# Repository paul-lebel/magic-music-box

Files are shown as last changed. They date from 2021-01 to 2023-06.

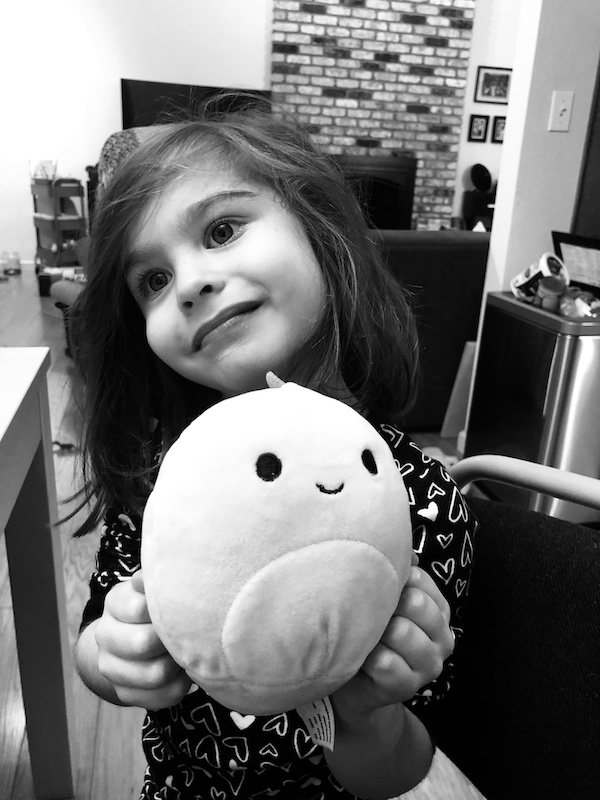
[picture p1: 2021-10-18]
Photos/SiaAndDave.jpg

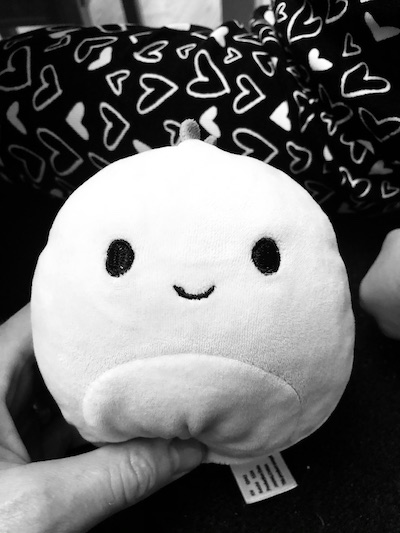
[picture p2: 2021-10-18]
Photos/Dave.jpg

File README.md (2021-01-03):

# magic-music-box
A small platform for parent-configurable child entertainment and education.

## Features
1. A small box with a simple screen, UI buttons, an audio system, and a lighting system.
2. A software platform that allows parents to create custom quiz questions (eg. "What does 5+5 equal?") or games.
3. A text to speech module reads the input prompts aloud through the audio speaker for children too young to read.
4. A bluetooth module allows for music streaming to the device from a parent's cellphone.
5. Computer control of the lighting system enhances the user experience for the child.
6. Customization of the underlying PCB's silkscreen artwork is displayed through a transparent front panel.

## Requirements
RPi.GPIO, inky, gTTS, circuitpython, adafruit-circuitpython-neopixel, font_fredoka_one

## Installation
This module was developed on Raspberry Pi Zero W V1.1, but should be compatible with all newer RPi models running the latest version of Raspbian OS.
1. Ensure the OS is updated, and also ensure that Python 3 is used by default. Following the instructions here takes care of this as well as circuitpython installation: <br>
https://learn.adafruit.com/circuitpython-on-raspberrypi-linux/installing-circuitpython-on-raspberry-pi
2. Follow these instructions to install inky: <br>
https://learn.pimoroni.com/tutorial/sandyj/getting-started-with-inky-phat
3. Add the following lines to /boot/config.txt: <br>
dtoverlay=audremap, enable_jack=on <br>
dtoverlay=audremap, pins_18_19=on <br>
dtoverlay=spi1-3cs <br>
4. Download / clone this repository
5. Navigate to the base of the repository
6. Install setuptools (__pip install setuptools__)
7. Install module (__pip install .__)

## Updating Module from Repository
1. Pull changes from remote repository
2. Activate virtual environment with previous install
3. Navigate to the module directory
4. Test the module for completeness (__python setup.py test__)
5. Update module (__pip install . --upgrade__)

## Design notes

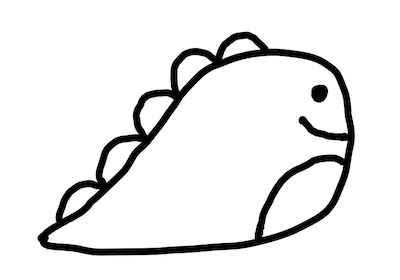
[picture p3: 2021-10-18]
Photos/Dave.png

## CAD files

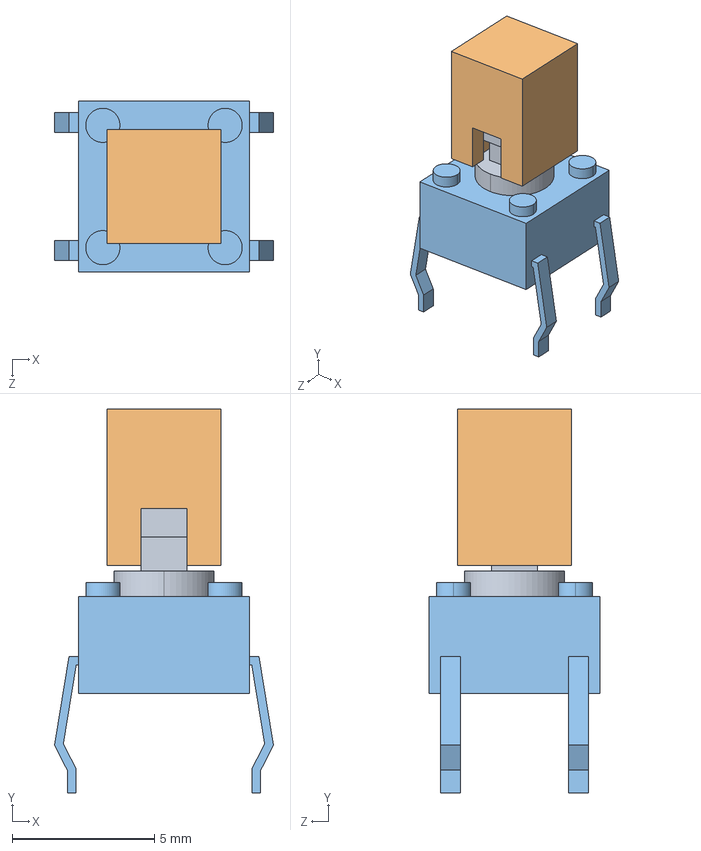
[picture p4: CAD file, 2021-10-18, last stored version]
RainbowPlay/B3F-1052/B3F-1052.step
7.70 x 13.5 x 6.00 mm
B3F_1052_BUTTON
B32_1000
B3F_1052_BASE

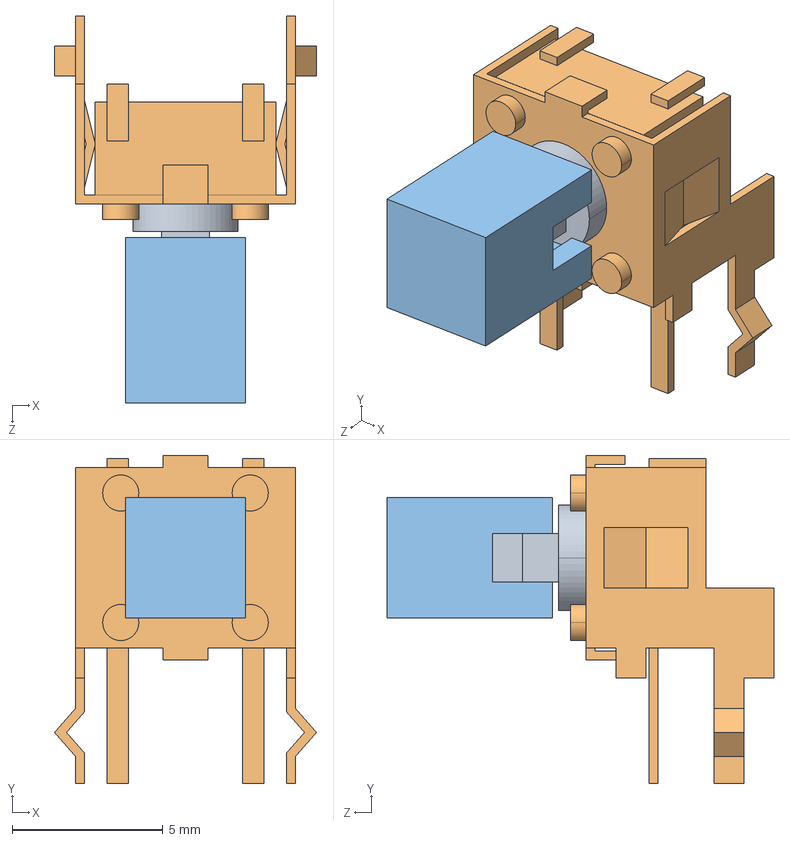
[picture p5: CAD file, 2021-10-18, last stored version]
RainbowPlay/B3F-3152/B3F-3152.step
8.70 x 10.9 x 12.9 mm
B3F_3152_BUTTON
B3F_3152_BASE
B32_1000

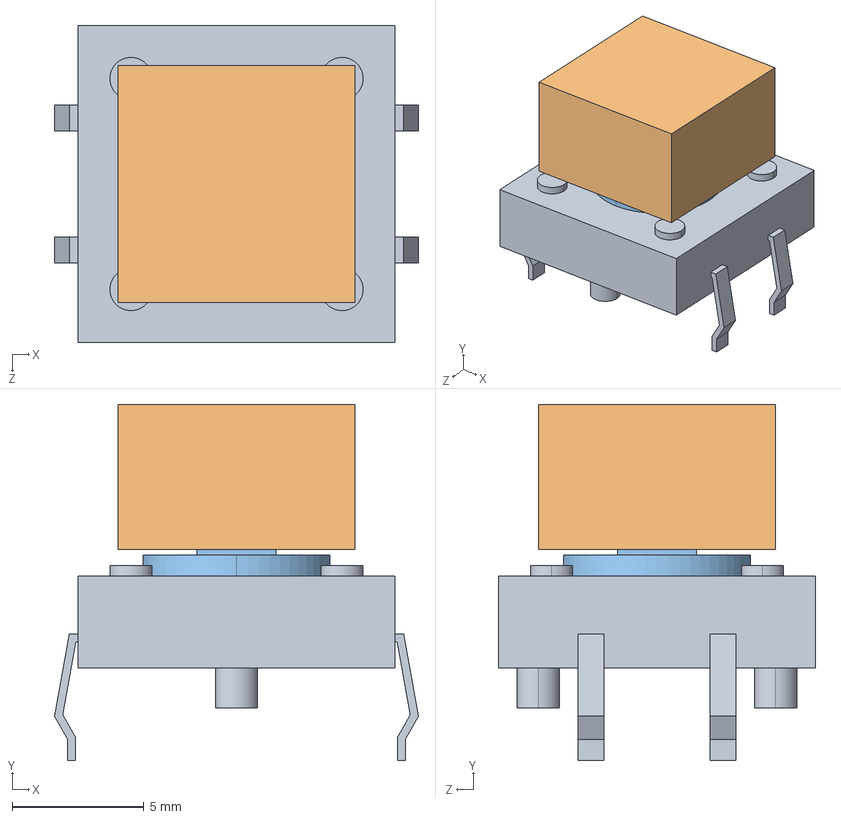
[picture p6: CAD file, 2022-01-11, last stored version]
RainbowPlay/B3F-4050/B3F-4050.step
13.8 x 13.5 x 12.0 mm
B3F_4050_BASE
B32_1200
B3F_4050_BUTTON

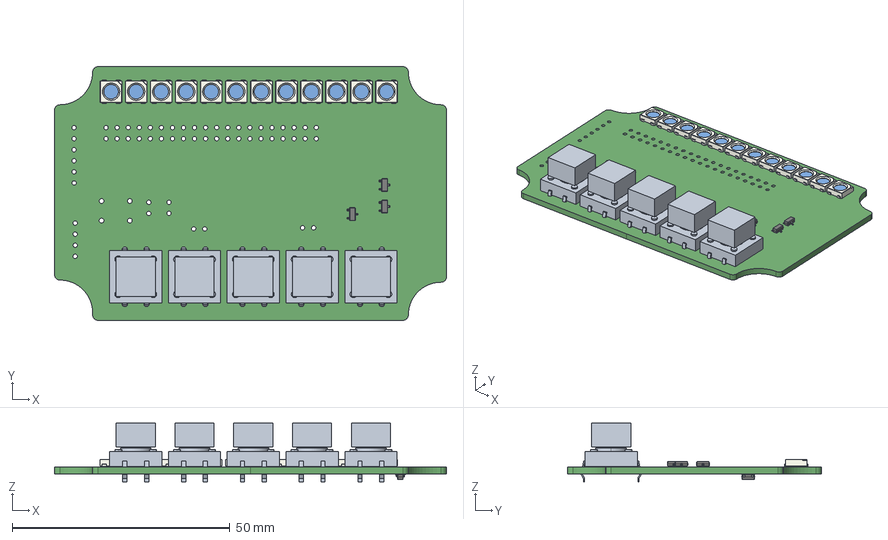
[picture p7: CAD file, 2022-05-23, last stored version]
RainbowPlay/RainbowPlay.step
90.0 x 58.2 x 13.5 mm

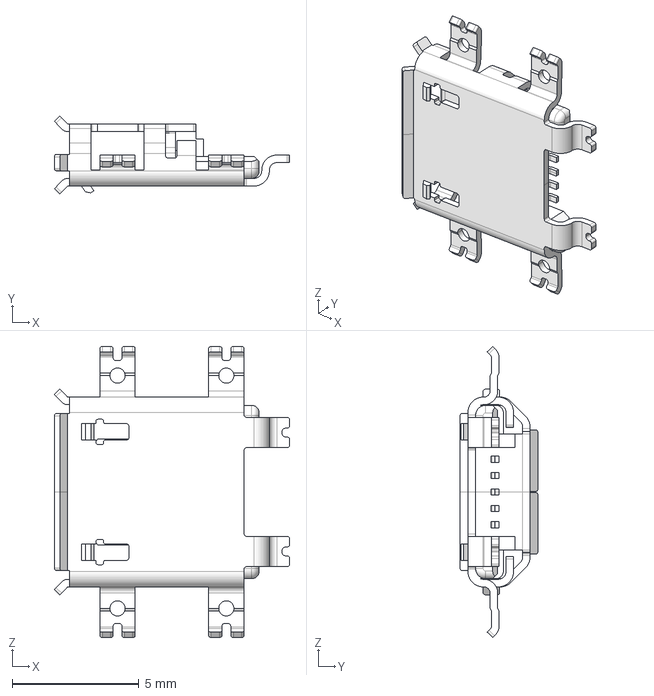
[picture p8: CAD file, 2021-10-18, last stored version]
RainbowPlay/ZX62M-B-5P/ZX62M-B-5P.stp
9.29 x 3.08 x 11.5 mm

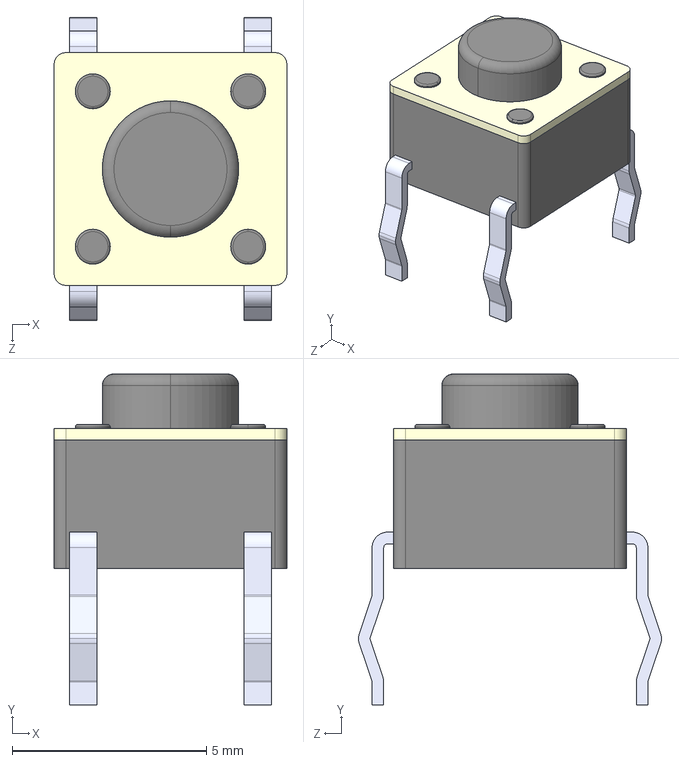
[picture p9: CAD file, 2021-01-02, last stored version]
RainbowPlay/1825910-6--3DModel-STEP-56544.STEP
5.99 x 8.52 x 7.80 mm

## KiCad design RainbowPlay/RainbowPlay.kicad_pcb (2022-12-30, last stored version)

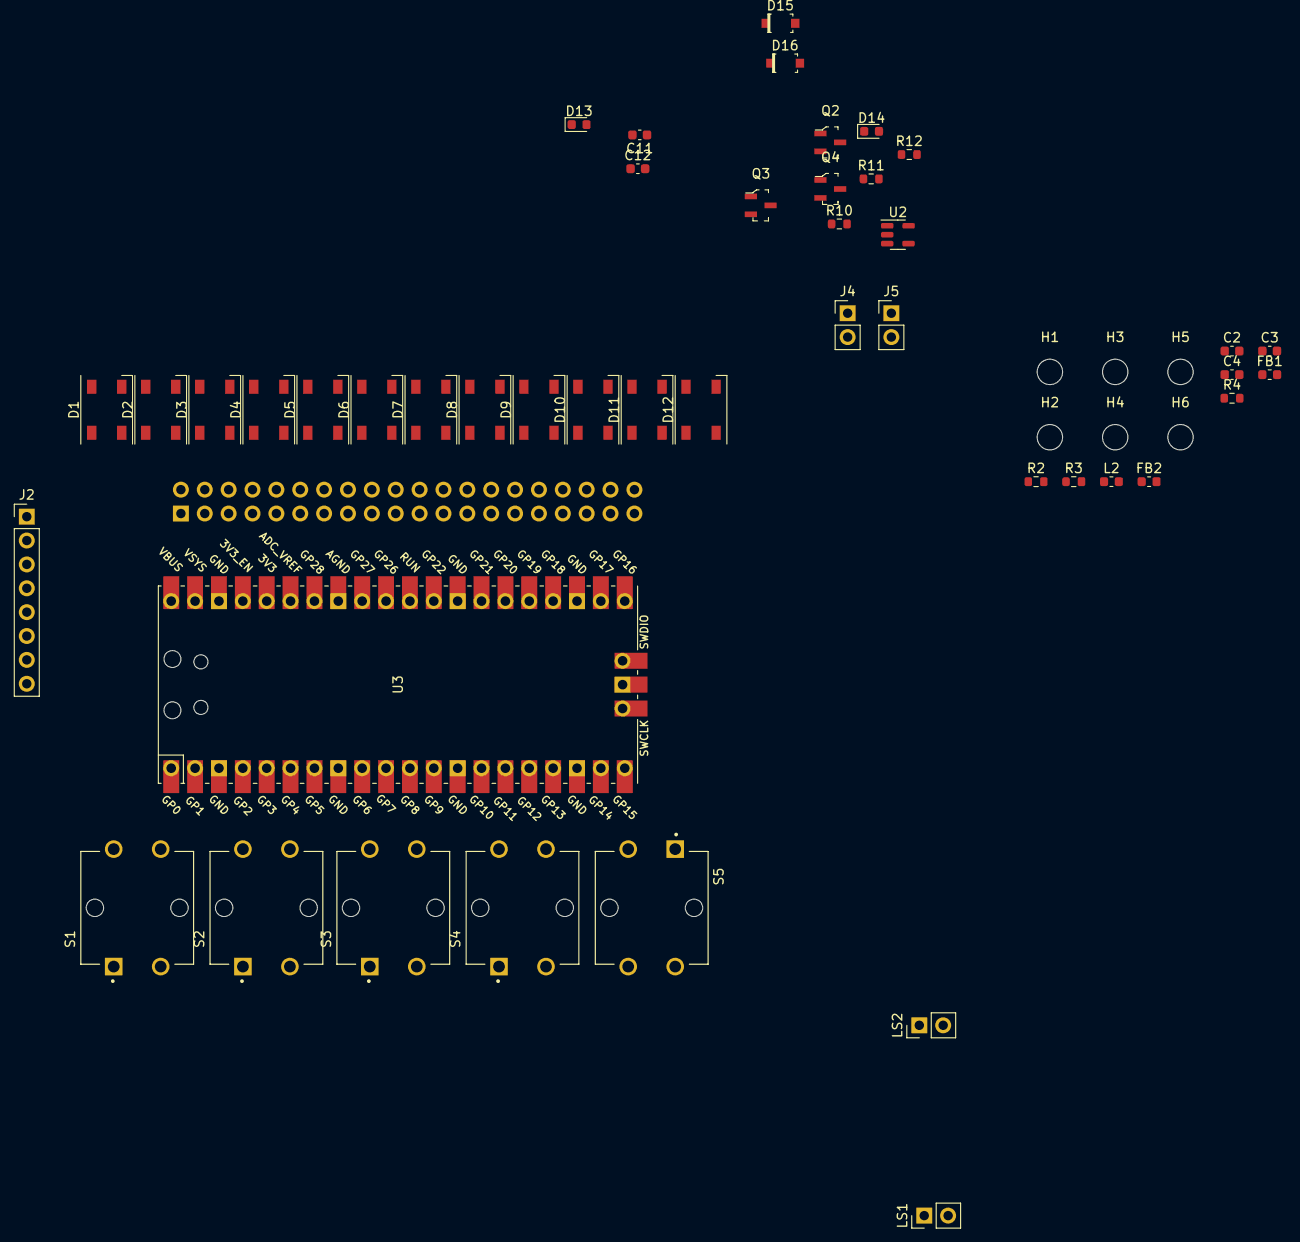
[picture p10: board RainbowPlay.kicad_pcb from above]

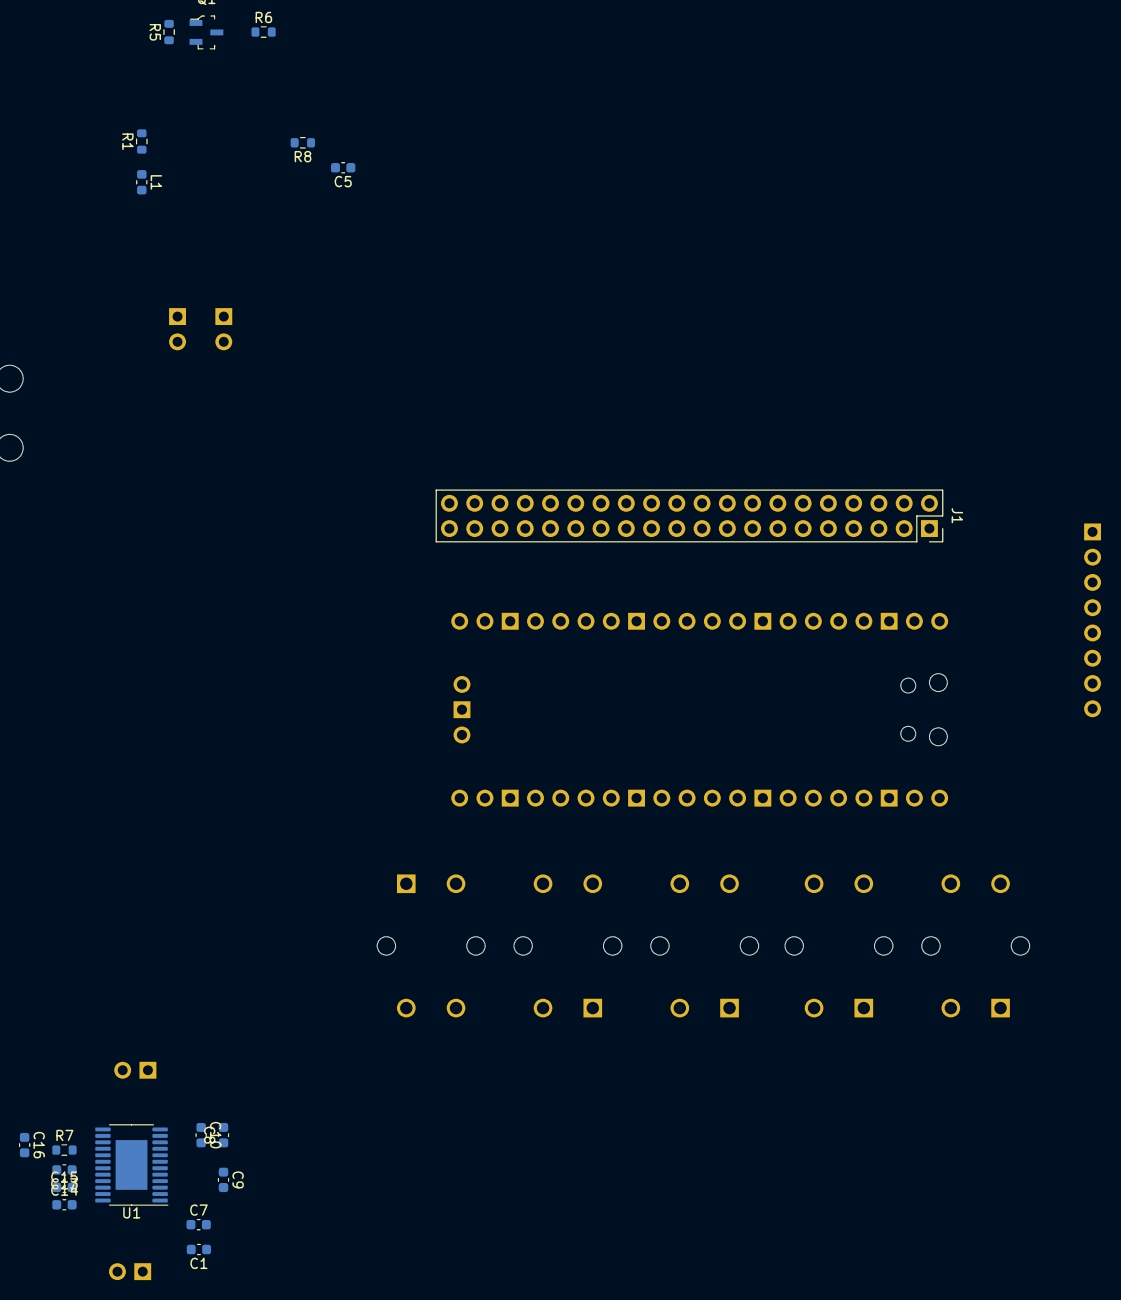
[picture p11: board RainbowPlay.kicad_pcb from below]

Board: 4 copper layers, 70 parts (19 on the bottom side), 52 nets, no tracks yet.

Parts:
C1, C2: 1.5uF; C_0603_1608Metric
C3, C4, C5, C7, C15, C16: 10uF; C_0603_1608Metric
C8, C9, C11, C12, C13: 0.1uF; C_0603_1608Metric
C10: 220pF; C_0603_1608Metric
C14: 1uF; C_0603_1608Metric
D1, D2, D3, D4, D5, D6, D7, D8, D9, D10, D11, D12: SK6812; LED_SK6812_PLCC4_5.0x5.0mm_P3.2mm
D13, D14: LED; LED_0603_1608Metric
D15, D16: 1N5819HW-7-F; SOD-123
FB1, FB2: FerriteBead_Small; L_0603_1608Metric
H1, H2, H3, H4, H5, H6: MountingHole; MountingHole_2.7mm
J1: GPIO_CONNECTOR; PinSocket_2x20_P2.54mm_Vertical
J2: Conn_01x08_Male; PinHeader_1x08_P2.54mm_Vertical
J4, J5: Conn_01x02_Male; PinHeader_1x02_P2.54mm_Vertical
L1, L2: 10uH; L_0603_1608Metric
LS1, LS2: Speaker; PinHeader_1x02_P2.54mm_Vertical
Q1, Q2, Q3, Q4: BSS138; SOT-23-3
R1, R3: 5R; R_0603_1608Metric
R2, R4, R5, R6, R11, R12: 10k; R_0603_1608Metric
R7: 120k; R_0603_1608Metric
R8, R10: 200R; R_0603_1608Metric
S1, S2, S3, S4, S5: B3F-4050; SW_B3F-4050
U1: TPA2001D2; HTSSOP-24-1EP_4.4x7.8mm_P0.65mm_EP3.2x5mm
U2: SN74LVC1G32DBVRG4; SOT-23-5
U3: Pico; RPi_Pico_SMD_TH

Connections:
+3V3: J1.1, Q1.1 (G), R2.2, R5.2, U2.5 (Vcc)
+5V: D1.3 (VDD), D2.3 (VDD), D3.3 (VDD), D4.3 (VDD), D5.3 (VDD), D6.3 (VDD), D7.3 (VDD), D8.3 (VDD), D9.3 (VDD), D10.3 (VDD), D11.3 (VDD), D12.3 (VDD), D13.2 (A), D15.K, D16.K, FB2.2, J1.2, J1.4, J2.1, J4.1, J5.1, R6.2, U3.39 (VSYS)
+5VA: C8.1, C9.1, C11.2, C12.1, C13.1, C15.2, C16.2, FB2.1, U1.4 (PV_DD), U1.9 (PV_DD), U1.10 (~SHUTDOWN), U1.16 (PV_DD), U1.19 (V_DD), U1.21 (PV_DD)
/AUD_L+: C3.1, U1.20 (LINP)
/AUD_L-: C4.1, U1.5 (LINN)
/AUD_R+: C5.1, U1.17 (RINP)
/AUD_R-: C7.1, U1.8 (RINN)
/AWAKE_SIG: D14.2 (A), J1.38, Q2.1 (G), R4.1, U2.1 (A)
/BTN_A: J1.11, S1.1, S1.2
/BTN_B: J1.13, S2.1, S2.2
/BTN_C: J1.27, S3.1, S3.2
/BTN_D: J1.29, S4.1, S4.2
/BTN_E: J1.31, S5.1, S5.2
/GAIN_0: J1.35, U1.3 (GAIN0)
/GAIN_1: J1.37, U1.15 (GAIN1)
/LO_BATT: J1.7, J2.8
/M1: J1.28, Q3.1 (G), R11.2
/M2: J1.36, Q4.1 (G), R12.2
/NEO: Q1.2 (S), R5.1, U3.1 (GPIO0)
/PWM_AUDIO_L: J1.32, R3.2
/PWM_AUDIO_R: J1.33, R1.2
/PWR_BTN: J1.40, R2.1, U2.2 (B)
/SPK_L+: LS1.2, U1.23 (LOUTP)
/SPK_L-: LS1.1, U1.2 (LOUTN)
/SPK_R+: LS2.2, U1.14 (ROUTP)
/SPK_R-: LS2.1, U1.11 (ROUTN)
GND: J1.20, J2.4, Q2.2 (S), R4.2, R10.1, S1.3, S1.4, S2.3, S2.4, S3.3, S3.4, S4.3, S4.4, S5.3, S5.4, U2.3 (GND), U3.28 (GND)
GND1: C8.2, C10.1, C11.1, C12.2, C13.2, C14.1, C15.1, C16.1, D1.1 (VSS), D2.1 (VSS), D3.1 (VSS), D4.1 (VSS), D5.1 (VSS), D6.1 (VSS), D7.1 (VSS), D8.1 (VSS), D9.1 (VSS), D10.1 (VSS), D11.1 (VSS), D12.1 (VSS), FB1.2, Q2.3 (D), Q3.2 (S), Q4.2 (S), R7.1, R8.1, R11.1, R12.1, U1.1 (PGND), U1.12 (PGND), U1.13 (PGND), U1.24 (PGND)
GNDA: C1.2, C2.2, C4.2, C7.2, C9.2, FB1.1, U1.6 (AGND)
unnamed: C1.1, C5.2, L1.2
unnamed: C2.1, C3.2, L2.2
unnamed: C10.2, U1.7 (COSC)
unnamed: C14.2, U1.22 (BYPASS)
unnamed: D1.2 (DIN), Q1.3 (D), R6.1
unnamed: D1.4 (DOUT), D2.2 (DIN)
unnamed: D2.4 (DOUT), D3.2 (DIN)
unnamed: D3.4 (DOUT), D4.2 (DIN)
unnamed: D4.4 (DOUT), D5.2 (DIN)
unnamed: D5.4 (DOUT), D6.2 (DIN)
unnamed: D6.4 (DOUT), D7.2 (DIN)
unnamed: D7.4 (DOUT), D8.2 (DIN)
unnamed: D8.4 (DOUT), D9.2 (DIN)
unnamed: D9.4 (DOUT), D10.2 (DIN)
unnamed: D10.4 (DOUT), D11.2 (DIN)
unnamed: D11.4 (DOUT), D12.2 (DIN)
unnamed: D13.1 (K), R8.2
unnamed: D14.1 (K), R10.2
unnamed: D15.A, J4.2, Q3.3 (D)
unnamed: D16.A, J5.2, Q4.3 (D)
unnamed: L1.1, R1.1
unnamed: L2.1, R3.1
unnamed: R7.2, U1.18 (ROSC)

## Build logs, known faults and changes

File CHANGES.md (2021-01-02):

# Release notes

All notable changes to this project will be documented in this file. This module adheres to [Semantic Versioning](https://semver.org/).

## 0.0.1
- Add initial files for RainbowPlay PCB
- Add README.md, setup.py, __init__.py
- Add this file
- Begin work on magic_box

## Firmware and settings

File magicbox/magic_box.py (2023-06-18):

#! /usr/bin/env python3
""" MagicBox class definition

-- Important Links --


-- Application Notes --


"""

import RPi.GPIO as GPIO
from magicbox.box_constants import * 
from transitions.instrument import ThreadedInstrument
from transitions.decorators import lock_no_block
from box_sm import *

import threading, queue
import time
import enum
import sys



class MagicBox():
    def __init__(self):

        super().__init__(self, \
            states = States, \
            transitions=SM_TRANSITIONS, \
            initial=States.MAIN_MENU, \
            ignore_invalid_triggers = True, \
            after_state_change = self.print_state, \
            auto_transitions = False, \
            name='Magic Music Box')
        
        # Create threaded queues for operations that block execution
        self._queues = {'keyInput': {'q': queue.Queue(maxsize=3), 'func': self._parse_key_input}}
        
        self.get_graph().draw('magic_box_diagram.png', prog='dot')

        # Set gpio pin numbering to the gpio pin numbers on the raspberry pi
        GPIO.setmode(GPIO.BCM)
        GPIO.setwarnings(False)
        GPIO.setup(self._buttonA, GPIO.IN, pull_up_down=GPIO.PUD_UP)
        GPIO.setup(self._buttonB, GPIO.IN, pull_up_down=GPIO.PUD_UP)
        GPIO.setup(self._buttonC, GPIO.IN, pull_up_down=GPIO.PUD_UP)
        GPIO.setup(self._buttonD, GPIO.IN, pull_up_down=GPIO.PUD_UP)
        GPIO.setup(self._buttonE, GPIO.IN, pull_up_down=GPIO.PUD_UP)

        self._screen = MagicBoxScreen()
        self._screen.displayMessage("Welcome!")


    def start_key_input(self):
        self._queues['keyInput']['q'].put_nowait({'prompt': 'Enter an input:'})
        return


if __name__ == "__main__":
    mb = MagicBox()
    try:
        while True:
            pass
    except KeyboardInterrupt:
        pass
    finally:
        GPIO.cleanup()

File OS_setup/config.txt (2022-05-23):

 # For more options and information see
# http://rpf.io/configtxt
# Some settings may impact device functionality. See link above for details

# uncomment if you get no picture on HDMI for a default "safe" mode
#hdmi_safe=1

# uncomment this if your display has a black border of unused pixels visible
# and your display can output without overscan
#disable_overscan=1

# uncomment the following to adjust overscan. Use positive numbers if console
# goes off screen, and negative if there is too much border
#overscan_left=16
#overscan_right=16
#overscan_top=16
#overscan_bottom=16

# uncomment to force a console size. By default it will be display's size minus
# overscan.
#framebuffer_width=1280
#framebuffer_height=720

# uncomment if hdmi display is not detected and composite is being output
#hdmi_force_hotplug=1

# uncomment to force a specific HDMI mode (this will force VGA)
#hdmi_group=1
#hdmi_mode=1

# uncomment to force a HDMI mode rather than DVI. This can make audio work in
# DMT (computer monitor) modes
#hdmi_drive=2

# uncomment to increase signal to HDMI, if you have interference, blanking, or
# no display
#config_hdmi_boost=4

# uncomment for composite PAL
#sdtv_mode=2

#uncomment to overclock the arm. 700 MHz is the default.
#arm_freq=800

# Uncomment some or all of these to enable the optional hardware interfaces
dtparam=i2c_arm=on
dtparam=i2s=on
dtparam=spi=on
enable_uart=1

# Uncomment this to enable infrared communication.
#dtoverlay=gpio-ir,gpio_pin=17
#dtoverlay=gpio-ir-tx,gpio_pin=18

# Additional overlays and parameters are documented /boot/overlays/README

# Enable audio (loads snd_bcm2835)
dtparam=audio=on
dtoverlay=audremap, enable_jack=on
dtoverlay=audremap, pins_18_19=on
dtoverlay=spi1-3cs

# Tell pin GPIO20 to go low on poweroff
dtoverlay=gpio-poweroff, gpiopin=20

[pi4]
# Enable DRM VC4 V3D driver on top of the dispmanx display stack
dtoverlay=vc4-fkms-v3d
max_framebuffers=2

[all]
#dtoverlay=vc4-fkms-v3d
start_x=0
gpu_mem=128
dtparam=act_led_trigger=actpwr

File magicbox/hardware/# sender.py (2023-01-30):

# sender.py
import time
import serial
ser = serial.Serial(
  port='/dev/ttyS0', # Change this according to connection methods, e.g. /dev/ttyUSB0
  baudrate = 115200,
  parity=serial.PARITY_NONE,
  stopbits=serial.STOPBITS_ONE,
  bytesize=serial.EIGHTBITS,
  timeout=1
)
msg = ""
i = 0

while True:
    i+=1
    print("Counter {} - Hello from Raspberry Pi".format(i))
    ser.write('hello'.encode('utf-8'))
    time.sleep(2)

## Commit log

2021-01-02 Initial commit
    - Add initial files for RainbowPlay PCB
    - Add README.md, setup.py, __init__.py
    - Add changes.md
    - Begin work on magic_box
    [1825910-6--3DModel-STEP-56544.STEP, RainbowPlay.kicad_pcb, RainbowPlay.sch]
2021-01-03 Update magic_box.py
    Fix indentation
    [magic_box.py]
2021-01-03 Fix import issues. Working basic init test.
    [magic_box.py]
2021-10-18 Initial development in progress
    [1825910-6--3DModel-STEP-56544.STEP, B3F-1052--3DModel-STEP-273799.STEP, B3F-1052.step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]
2022-05-23 PCB dev
    - Work on power up, power down
    [RainbowPlay.kicad_pcb, RainbowPlay.sch, RainbowPlay.step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]
2022-07-05 Update power/ground strategy
    - Use single power button
    - Do not disable Powerboost. Just enable/disable devices on PCB to save power when asleep
    - Add LO_BATT input
    - Clarify schematic layout of audio filtering
2022-07-30 Add pico
    - Add pico
    - Add example neopixel code
    - Test neopixel with pico (works)
    [RainbowPlay.kicad_sch, RainbowPlay.sch]
2023-01-30 Another pivot
    - Change to external USB battery pack (cell phone charger w/ 8000 mA-hrs and higher I_peak). This alleviates constraints if running 2 motors at 300 mA each, with LEDs
    - Change to DRV8833 to operate motors, with pico generating PWM
    - Simplified power strategy: power down only through software. Power control using simple rocker switch and read-only SD card to protect against corruption.
2023-02-19 Remove electronics and add test scripts
    [1825910-6--3DModel-STEP-56544.STEP, B3F-1052--3DModel-STEP-273799.STEP, B3F-1052.step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]
2023-02-19 Remove kicad files
2023-02-19 Silly screen offset fix
    [button_test.py]
2023-02-19 Update sia-clock-tft.py
    fix missing reference
    [sia-clock-tft.py]
2023-02-19 Update sia-clock-tft.py
    silly bug
    [sia-clock-tft.py]
2023-02-19 Update sia-clock-tft.py
    another silly bug
    [sia-clock-tft.py]
2023-02-19 Update sia-clock-tft.py
    missing font definition
    [sia-clock-tft.py]
2023-02-19 Update sia-clock-tft.py
    - Remove black rectangle display to avoid flashing
    - Test red clock (temp)
    [sia-clock-tft.py]
2023-02-19 Update sia-clock-tft.py
    Revert to 7:30pm bedtime
    [sia-clock-tft.py]
2023-02-19 Add backlight button and weather update interval
2023-02-19 Update sia-clock-tft.py
    More silly fixes
    [sia-clock-tft.py]
2023-02-19 Update sia-clock-tft.py
    More fixes
    [sia-clock-tft.py]
2023-02-19 Update sia-clock-tft.py
    Add falling edge logic so screen doesn't always turn off
    [sia-clock-tft.py]
2023-02-20 Update sia-clock-tft.py
    Silly bug fix
    [sia-clock-tft.py]
2023-02-20 Update sia-clock-tft.py
    - Revert to actual weather indication
    - add temperature color
    [sia-clock-tft.py]
2023-02-20 Update sia-clock-tft.py
    Fix silly bug
    [sia-clock-tft.py]
2023-02-21 Update sia-clock-tft.py
    Fix weekday time comparison
    [sia-clock-tft.py]
2023-03-09 Update sia-clock-tft.py
    add print statement for loop time
2023-03-09 Update sia-clock-tft.py
    add other print statements
2023-06-18 Continue refactoring
    [config.txt]

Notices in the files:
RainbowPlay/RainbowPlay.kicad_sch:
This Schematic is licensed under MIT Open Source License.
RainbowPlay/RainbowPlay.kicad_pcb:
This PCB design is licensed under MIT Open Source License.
